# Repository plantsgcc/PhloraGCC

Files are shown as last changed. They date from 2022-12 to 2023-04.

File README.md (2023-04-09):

# PhobGCCv2-HW
Seperate repository for the hardware used in the PhobGCC v2.0

The PhobGCC v2.0 board is licensed under CERN Open Hardware Licence Version 2 - Strongly Reciprocal.
This means that any changes made to the board should be made public and CHANGES.txt be updated to reflect said changes.

--

PhloraGCC v2.0.2

-aesthetic changes 

-left z + routing to RP2040 directly

-repositioned L and R through holes for easier alignment, especially with JST 2 pin headers

-USB-C in place of Micro USB for flashing

-changed start pad shape to emulate d-pad, expanded D-Pad + Start pads a smidge

-thru-holes on ABXY pads for easy installation and implementation of Tactile Push Button switch usage (6x6mm form factor)

-integration of experimental Phob 2.0.3 ESD protection circuit; 47uF Polarized Capacitor, 30v 1a Schottky Diode, Unidirectional Zener Diode

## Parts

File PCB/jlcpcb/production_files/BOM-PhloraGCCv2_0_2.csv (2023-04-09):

Comment | Designator | Footprint | LCSC
1k | R18 | C_0402_1005Metric | C11702
C_Polarized | C1 | CP_EIA-3528-12_Kemet-T_Pad1.50x2.35mm_HandSolder | C141304
CUS10S30,H3F | D5 | D_SOD-323 | C146335
Q_PMOS_GDS | Q2 | SOT-23 | C15127
100n | C17,C19,C20,C22,C24,C25,C26,C27,C28,C29,C30,C31,C32 | C_0402_1005Metric | C1525
27p | C14,C15 | C_0402_1005Metric | C1557
10u | C16,C18 | C_0805_2012Metric | C15850
316 | R10,R19,R24,R25 | R_0402_1005Metric | C159037
0.047u | C3,C4,C5,C6,C7,C8 | C_0603_HandSoldering | C1622
RP2040 | U8 | RP2040-QFN-56 | C2040
Q_NMOS_GSD | Q1,Q3 | SOT-23 | C20917
100R | R11,R12 | R_0603_1608Metric_Pad0.98x0.95mm_HandSolder | C22775
2k | R3,R4,R5,R6 | R_0603_1608Metric_Pad0.98x0.95mm_HandSolder | C22975
27 | R20,R21 | C_0402_1005Metric | C25100
10k | R13,R14,R15 | R_0603_1608Metric_Pad0.98x0.95mm_HandSolder | C25804
5.1k | R16,R17 | R_0402_1005Metric_Pad0.72x0.64mm_HandSolder | C25905
DRV5055A2xDBZxQ1 | U4,U9 | SOT-23 | C266128
DRV5055A2xDBZxQ1 | U10,U11 | SOT-23 | C266131
BOOTSEL | S1 | SW_TS-1187A-B-A-B | C318884
180 | R1,R2,R7,R8,R9 | R_0402_1005Metric | C38941
Crystal_GND24 | Y1 | Crystal_SMD_3225-4Pin_3.2x2.5mm | C403945
GCT_USB4056-03-A_REVA | J8 | GCT_USB4056-03-A_REVA | C456013
D_Zener | D3,D4 | D_SMA | C499814
1u | C21,C23 | C_0402_1005Metric | C52923
MCP3002 | U1,U3 | SOIC-8_3.9x4.9mm_P1.27mm | C56997
AMS1117-3.3 | U6 | SOT-223-3_TabPin2 | C6186
Fuse | F1 | Fuse_1206_3216Metric | C69680
MBR0520 | D1 | D_SOD-123 | C77335
M7C | D2 | D_SOD-123 | C8598
W25Q128JVS | U7 | SOIC-8_5.23x5.23mm_P1.27mm | C97521
A | SW1 | ABXY_Contact_Omron_Switch
Z | SW8 | Z_Switch_Edge_Omron
Dleft | SW9 | Dpad_Contact_TL3315NF_2
Dup | SW10 | Dpad_Contact_TL3315NF_2
Dright | SW11 | Dpad_Contact_TL3315NF_2
Ddown | SW12 | Dpad_Contact_TL3315NF_2
Stickbox_Assembly_Main | U2 | GCC_Stickbox_Hall_Only
5.2mm | H1 | MountingHole_5.2mm
2mm | H3 | MountingHole_2.0mm
1.8mm | H5 | MountingHole_1.8mm
1.8mm | H6 | MountingHole_1.8mm
2.4mm | H7 | MountingHole_2.4mm
2mm | H4 | MountingHole_2.0mm
2.2mm | H8 | MountingHole_2.2mm
Slot | H2 | Slot
2.2mm | H9 | MountingHole_2.2mm
B | SW2 | ABXY_Contact_Omron_Switch
X | SW3 | ABXY_Contact_Omron_Switch
ZL | SW8L | Z_Switch_Edge_Omron
Start | SW5 | Dpad_Contact_TL3315NF_2
Conn_01x01 | J4 | PinHeader_1x01_P2.54mm_Vertical
MouseBite | H14 | breakaway-mousebites-double-v2-small
Stickbox_Assembly_CStick | U5 | GCC_Stickbox_Hall_Only
MouseBite | H15 | breakaway-mousebites-double-v2-large
MountingHole | H11 | MountingHole_5.2mm
Conn_01x02 | J11 | PinHeader_1x02_P2.00mm_Vertical
MountingHole | H13 | MountingHole_2.0mm
MountingHole | H12 | MountingHole_2.0mm
MountingHole | H10 | MountingHole_1.8mm
Y | SW4 | ABXY_Contact_Omron_Switch
L | SW6 | Pin_Header_Straight_1x02_Pitch2.54mm
R | SW7 | Pin_Header_Straight_1x02_Pitch2.54mm
R_POT_MountingPin | RV2 | GCC_Slider
R_POT_MountingPin | RV1 | GCC_Slider
Conn_01x06_Female | J1 | GCC_Header_Straight_1x06_Pitch2.00mm
Conn_01x06 | J6 | PinSocket_1x06_P2.00mm_Vertical
Conn_01x06 | J15 | PinSocket_1x06_P2.00mm_Vertical
Rumble | J5 | rumble_pins
Conn_01x06 | J14 | PinSocket_1x06_P2.00mm_Vertical
Conn_01x02 | J2 | PinHeader_1x02_P2.00mm_Vertical

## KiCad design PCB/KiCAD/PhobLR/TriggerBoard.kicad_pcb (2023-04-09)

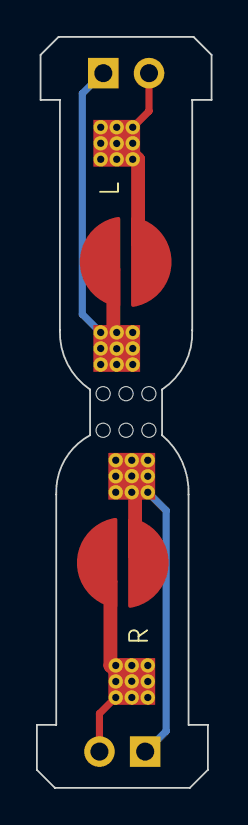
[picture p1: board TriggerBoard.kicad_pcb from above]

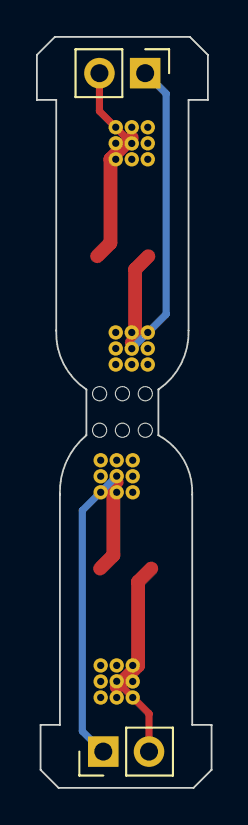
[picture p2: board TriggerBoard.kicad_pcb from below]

Board: 2 copper layers, 9.7 x 41.7 mm, 5 parts (2 on the bottom side), 4 nets.

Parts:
H2: MouseBiteRA; breakaway-mousebites-double
J1: L; Pin_Header_Straight_1x02_Pitch2.54mm
J2: R; Pin_Header_Straight_1x02_Pitch2.54mm
SW1: L; Trigger_Contact
SW2: R; Trigger_Contact

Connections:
unnamed: J1.1, SW1.1
unnamed: J1.2, SW1.2
unnamed: J2.1, SW2.1
unnamed: J2.2, SW2.2

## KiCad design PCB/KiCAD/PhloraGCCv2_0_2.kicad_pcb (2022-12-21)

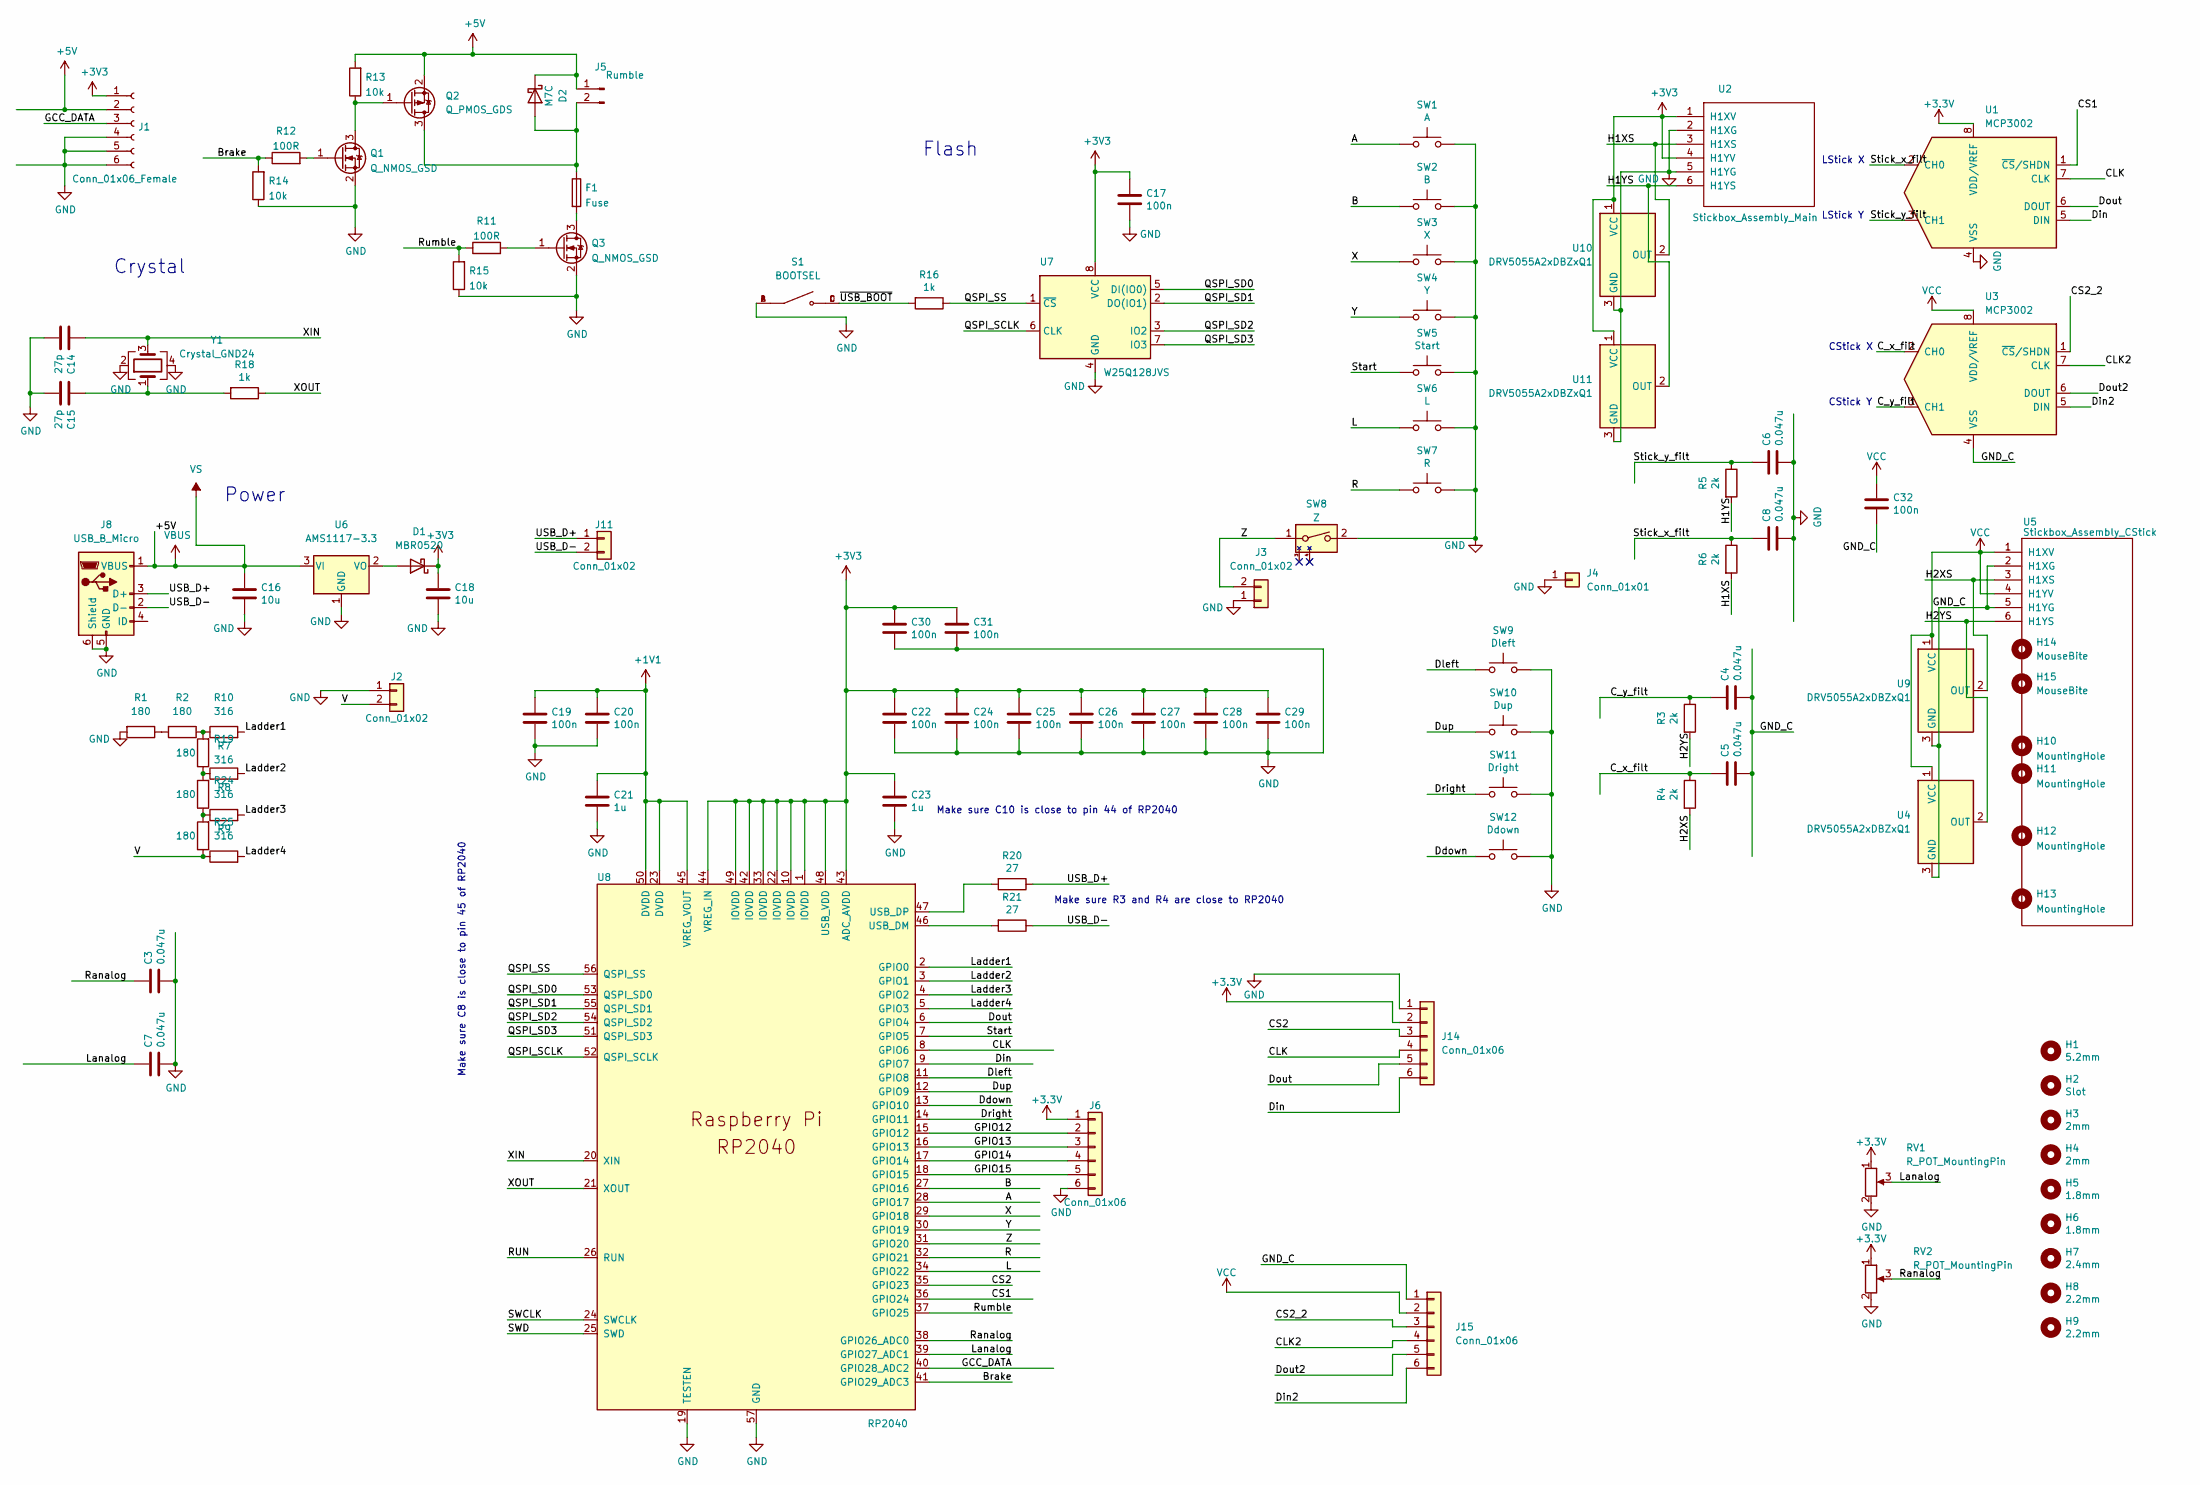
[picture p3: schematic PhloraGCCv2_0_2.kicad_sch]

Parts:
C3, C4, C5, C6, C7, C8: 0.047u; C_0603_HandSoldering; LCSC C1622
C14, C15: 27p; C_0402_1005Metric
C16, C18: 10u; C_0805_2012Metric
C17, C19, C20, C22, C24, C25, C26, C27, C28, C29, C30, C31, C32: 100n; C_0402_1005Metric
C21, C23: 1u; C_0402_1005Metric
D1: MBR0520; D_SOD-123
D2: M7C; D_SOD-123; LCSC C8598
F1: Fuse; Fuse_1206_3216Metric; LCSC C69680
H1: 5.2mm; MountingHole_5.2mm
H2: Slot
H3, H4: 2mm; MountingHole_2.0mm
H5, H6: 1.8mm; MountingHole_1.8mm
H7: 2.4mm; MountingHole_2.4mm
H8, H9: 2.2mm; MountingHole_2.2mm
H10: MountingHole; MountingHole_1.8mm
H11: MountingHole; MountingHole_5.2mm
H12, H13: MountingHole; MountingHole_2.0mm
H14: MouseBite; breakaway-mousebites-double-v2-small
H15: MouseBite; breakaway-mousebites-double-v2-large
J1: Conn_01x06_Female; GCC_Header_Straight_1x06_Pitch2.00mm
J2, J11: Conn_01x02; PinHeader_1x02_P2.00mm_Vertical
J3: Conn_01x02; PinHeader_1x02_P2.00mm_Horizontal
J4: Conn_01x01; PinHeader_1x01_P2.54mm_Vertical
J5: Rumble; rumble_pins
J6, J14, J15: Conn_01x06; PinSocket_1x06_P2.00mm_Vertical
J8: USB_B_Micro; USB_Micro-B_Amphenol_10118194_Horizontal
Q1, Q3: Q_NMOS_GSD; SOT-23; LCSC C20917
Q2: Q_PMOS_GDS; SOT-23; LCSC C15127
R1, R2, R7, R8, R9: 180; R_0402_1005Metric
R3, R4, R5, R6: 2k; R_0603_1608Metric_Pad0.98x0.95mm_HandSolder; LCSC C22975
R10, R19, R24, R25: 316; R_0402_1005Metric
R11, R12: 100R; R_0603_1608Metric_Pad0.98x0.95mm_HandSolder; LCSC C22775
R13, R14, R15: 10k; R_0603_1608Metric_Pad0.98x0.95mm_HandSolder; LCSC C25804
R16, R18: 1k; C_0402_1005Metric
R20, R21: 27; C_0402_1005Metric
RV1, RV2: R_POT_MountingPin; GCC_Slider
S1: BOOTSEL; SW_TS-1187A-B-A-B; PARTREV A0
SW1: A; ABXY_Contact_Omron_Switch
SW2: B; ABXY_Contact_Omron_Switch
SW3: X; ABXY_Contact_Omron_Switch
SW4: Y; ABXY_Contact_Omron_Switch
SW5: Start; Start_Contact
SW6: L; Pin_Header_Straight_1x02_Pitch2.54mm
SW7: R; Pin_Header_Straight_1x02_Pitch2.54mm
SW8: Z; Z_Switch_Edge_Omron
SW9: Dleft; Dpad_Contact_TL3315NF_2
SW10: Dup; Dpad_Contact_TL3315NF_2
SW11: Dright; Dpad_Contact_TL3315NF_2
SW12: Ddown; Dpad_Contact_TL3315NF_2
U1, U3: MCP3002; SOIC-8_3.9x4.9mm_P1.27mm
U2: Stickbox_Assembly_Main; GCC_Stickbox_Hall_Only
U4, U9, U10, U11: DRV5055A2xDBZxQ1; SOT-23
U5: Stickbox_Assembly_CStick; GCC_Stickbox_Hall_Only
U6: AMS1117-3.3; SOT-223-3_TabPin2
U7: W25Q128JVS; SOIC-8_5.23x5.23mm_P1.27mm
U8: RP2040; RP2040-QFN-56
Y1: Crystal_GND24; Crystal_SMD_3225-4Pin_3.2x2.5mm

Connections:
+1V1: C19.1, C20.1, C21.1, U8.23 (DVDD), U8.45 (VREG_VOUT), U8.50 (DVDD)
+5V: C16.1, D2.1 (K), J1.2, J5.1, J8.1 (VBUS), Q2.2 (S), R13.2, U6.3 (VI)
/A: SW1.1, U8.28 (GPIO17)
/B: SW2.1, U8.27 (GPIO16)
/Brake: R12.1, R14.2, U8.41 (GPIO29_ADC3)
/CLK: J14.4, U1.7 (CLK), U8.8 (GPIO6)
/CLK2: J15.4, U3.7 (CLK)
/CS1: U1.1 (~CS/SHDN), U8.36 (GPIO24)
/CS2: J14.3, U8.35 (GPIO23)
/CS2_2: J15.3, U3.1 (~CS/SHDN)
/C_x_filt: C5.1, R4.1, U3.2 (CH0)
/C_y_filt: C4.1, R3.1, U3.3 (CH1)
/Ddown: SW12.1, U8.13 (GPIO10)
/Din: J14.6, U1.5 (DIN), U8.9 (GPIO7)
/Din2: J15.6, U3.5 (DIN)
/Dleft: SW9.1, U8.11 (GPIO8)
/Dout: J14.5, U1.6 (DOUT), U8.6 (GPIO4)
/Dout2: J15.5, U3.6 (DOUT)
/Dright: SW11.1, U8.14 (GPIO11)
/Dup: SW10.1, U8.12 (GPIO9)
/GCC_DATA: J1.3, U8.40 (GPIO28_ADC2)
/GND_C: C4.2, C5.2, C32.2, J15.1, U3.4 (VSS), U4.3 (GND), U5.2 (H1XG), U5.5 (H1YG), U9.3 (GND)
/GPIO13: J6.3, U8.16 (GPIO13)
/GPIO14: J6.4, U8.17 (GPIO14)
/GPIO15: J6.5, U8.18 (GPIO15)
/H1XS: R6.2, U2.3 (H1XS), U10.2 (OUT)
/H1YS: R5.2, U2.6 (H1YS), U11.2 (OUT)
/H2XS: R4.2, U5.3 (H1XS), U9.2 (OUT)
/H2YS: R3.2, U4.2 (OUT), U5.6 (H1YS)
/L: SW6.1, U8.34 (GPIO22)
/Ladder1: R10.2, U8.2 (GPIO0)
/Ladder2: R19.2, U8.3 (GPIO1)
/Ladder3: R24.2, U8.4 (GPIO2)
/Ladder4: R25.2, U8.5 (GPIO3)
/Lanalog: C7.1, RV1.3 (Signal), U8.39 (GPIO27_ADC1)
/QSPI_SCLK: U7.6 (CLK), U8.52 (QSPI_SCLK)
/QSPI_SD0: U7.5 (DI(IO0)), U8.53 (QSPI_SD0)
/QSPI_SD1: U7.2 (DO(IO1)), U8.55 (QSPI_SD1)
/QSPI_SD2: U7.3 (IO2), U8.54 (QSPI_SD2)
/QSPI_SD3: U7.7 (IO3), U8.51 (QSPI_SD3)
/QSPI_SS: R16.1, U7.1 (~CS), U8.56 (QSPI_SS)
/R: SW7.1, U8.32 (GPIO21)
/RUN: U8.26 (RUN)
/Ranalog: C3.1, RV2.3 (Signal), U8.38 (GPIO26_ADC0)
/Rumble: R11.1, R15.2, U8.37 (GPIO25)
/SWCLK: U8.24 (SWCLK)
/SWD: U8.25 (SWD)
/Start: SW5.1, U8.7 (GPIO5)
/Stick_x_filt: C8.1, R6.1, U1.2 (CH0)
/Stick_y_filt: C6.1, R5.1, U1.3 (CH1)
/USB_D+: J8.3 (D+), J11.1, R20.1
/USB_D-: J8.2 (D-), J11.2, R21.1
/V: J2.2, R9.1, R25.1
/X: SW3.1, U8.29 (GPIO18)
/XIN: C14.1, U8.20 (XIN), Y1.3
/XOUT: R18.1, U8.21 (XOUT)
/Y: SW4.1, U8.30 (GPIO19)
/Z: J3.2, SW8.1, U8.31 (GPIO20)
/~USB_BOOT: R16.2, S1.C, S1.D
GND: C3.2, C6.2, C7.2, C8.2, C14.2, C15.2, C16.2, C17.2, C18.2, C19.2, C20.2, C21.2, C22.2, C23.2, C24.2, C25.2, C26.2, C27.2, C28.2, C29.2, C30.2, C31.2, J1.4, J1.5, J1.6, J2.1, J3.1, J4.1, J6.6, J8.5 (GND), J8.6 (Shield), J14.1, Q1.2 (S), Q3.2 (S), R1.2, R14.1, R15.1, RV1.2 (GND), RV2.2 (GND), S1.A, S1.B, SW1.2, SW2.2, SW3.2, SW4.2, SW5.2, SW6.2, SW7.2, SW8.2, SW9.2, SW10.2, SW11.2, SW12.2, U1.4 (VSS), U2.2 (H1XG), U2.5 (H1YG), U6.1 (GND), U7.4 (GND), U8.19 (TESTEN), U8.57 (GND), U10.3 (GND), U11.3 (GND), Y1.2, Y1.4; also elsewhere on the board
unnamed: C15.1, R18.2, Y1.1
unnamed: D1.2 (A), U6.2 (VO)
unnamed: D2.2 (A), F1.1, J5.2, Q2.3 (D)
unnamed: F1.2, Q3.3 (D)
unnamed: Q1.1 (G), R12.2
unnamed: Q1.3 (D), Q2.1 (G), R13.1
unnamed: Q3.1 (G), R11.2
unnamed: R1.1, R2.2
unnamed: R2.1, R7.2, R10.1
unnamed: R7.1, R8.2, R19.1
unnamed: R20.2, U8.47 (USB_DP)
unnamed: R21.2, U8.46 (USB_DM)
unnamed: R8.1, R9.2, R24.1
VCC: C32.1, J15.2, U3.8 (VDD/VREF), U4.1 (VCC), U5.1 (H1XV), U5.4 (H1YV), U9.1 (VCC)

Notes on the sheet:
Power
LStick Y
Make sure C10 is close to pin 44 of RP2040
CStick Y
Make sure R3 and R4 are close to RP2040
Make sure C8 is close to pin 45 of RP2040
Flash
Crystal
CStick X
LStick X

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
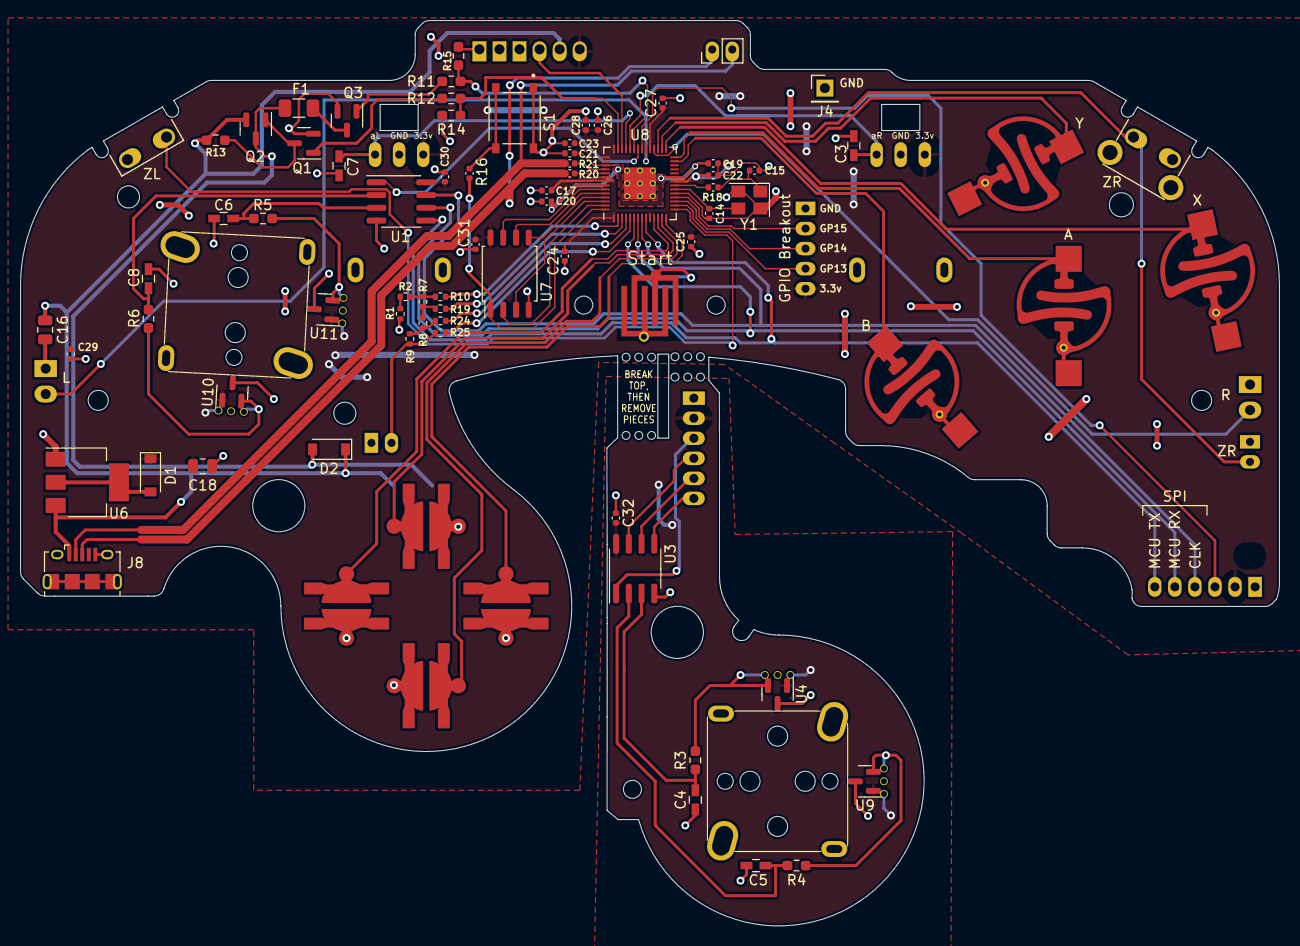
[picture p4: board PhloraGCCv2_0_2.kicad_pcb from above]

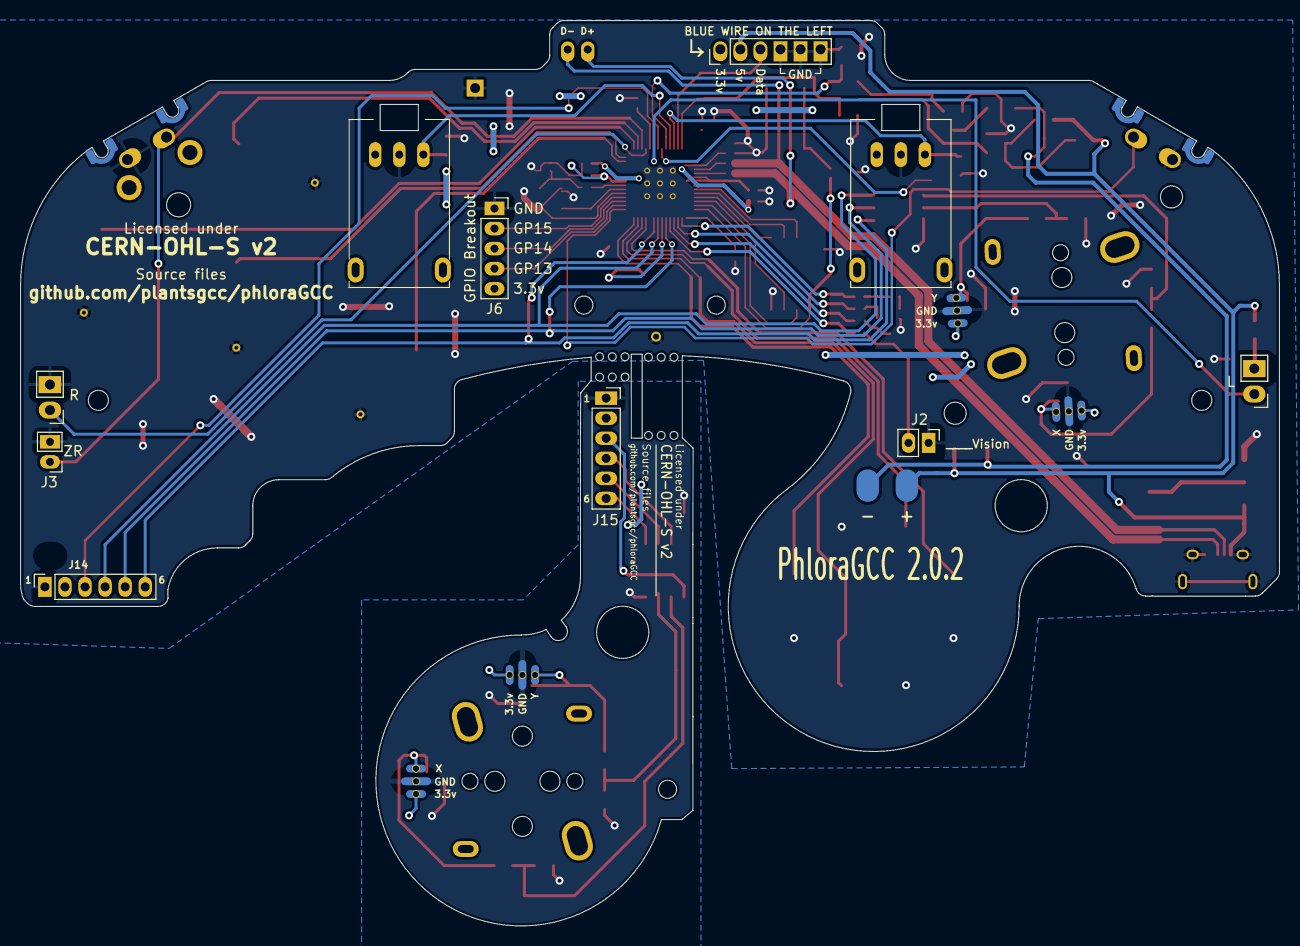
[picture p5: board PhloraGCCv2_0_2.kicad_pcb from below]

Board: 2 copper layers, 125.5 x 90.3 mm, 106 parts (11 on the bottom side), 73 nets.

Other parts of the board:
SW8L: ZL; Z_Switch_Edge_Omron

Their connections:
GND: SW8L.1; also elsewhere on the board

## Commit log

2022-12-21 Initial PhloraGCC v2.0.2 commit
    [PhloraGCCv2_0_2.kicad_pcb]
2022-12-21 File reorganization, fleshing out repository
    [PhloraGCCv2_0_2.kicad_sch, PhobGCC_2_0_0_proto_1.kicad_pcb, TriggerBoard.kicad_pcb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]
2023-04-09 push to commit
    committing the push with this commit
    [BOM-PhloraGCCv2_0_2.csv, PhloraGCCv2_0_2.kicad_sch, TriggerBoard.kicad_pcb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]

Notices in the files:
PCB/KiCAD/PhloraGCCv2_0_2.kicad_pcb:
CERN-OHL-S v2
